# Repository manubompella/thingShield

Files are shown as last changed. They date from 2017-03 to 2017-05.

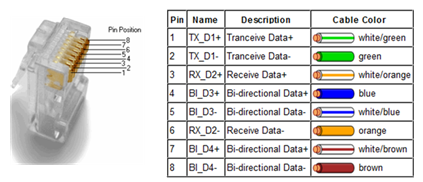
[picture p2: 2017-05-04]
thingShield-Bot/Reference/509802d016bce918a6f6cb5cf38a3232.png

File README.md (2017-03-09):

# Arduino XBee shield

The Arduino shield is designed to be used for multiple use cases without redesigning the hardware. 

## Platform Features

 * [XBee Compatible Socket](https://www.sparkfun.com/datasheets/Wireless/Zigbee/XBee-Dimensional.pdf)
 * TTL to CMOS level shifter
 * Compatible with UNO R3 headers
 * Ability to support multiple thingBot platforms
 
## Maintainers

The Arduino Xbee shield is maintained by thingTronics Innovations.

Main contributor:
 * Manohar Bompella @<manohar.bompella@thingtronics.com>
 * Lovelesh Patel @<lovelesh.patel@thingtronics.com>

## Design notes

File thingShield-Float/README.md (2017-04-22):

# thingFloat-Shield

The Arduino shield is designed to be used for water level floats without redesigning the hardware. 

## Platform Features

 * Compatible with UNO R3/MEGA headers
 
## Maintainers

The thingFloat-Shield is maintained by thingTronics Innovations.

Main contributor:
 * Manohar Bompella @<manohar.bompella@thingtronics.com>
 * Lovelesh Patel @<lovelesh.patel@thingtronics.com>

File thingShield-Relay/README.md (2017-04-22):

# thingRelay-Shield

The Arduino shield is designed to be used for relay without redesigning the hardware. 

## Platform Features

 * Compatible with UNO R3/MEGA headers
 
## Maintainers

The thingRelay-Shield is maintained by thingTronics Innovations.

Main contributor:
 * Manohar Bompella @<manohar.bompella@thingtronics.com>
 * Lovelesh Patel @<lovelesh.patel@thingtronics.com>

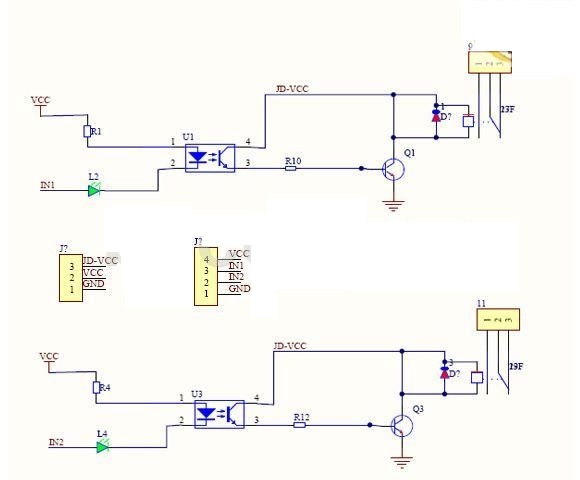
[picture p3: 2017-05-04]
thingShield-Float/Reference/schematic-1.jpg

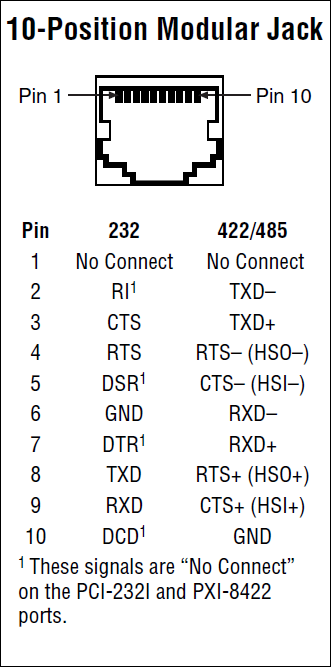
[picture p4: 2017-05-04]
thingShield-Bot/Reference/10PosModJack.png

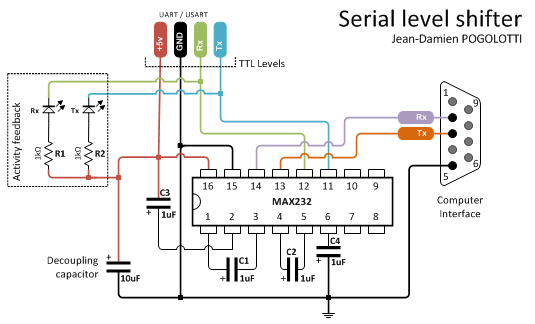
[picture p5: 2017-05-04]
thingShield-Bot/Reference/1449150794_serialshifter.png

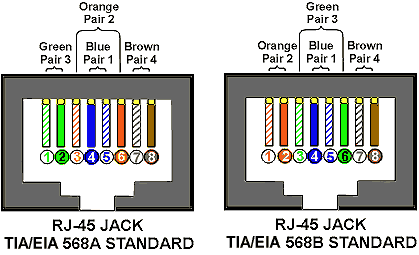
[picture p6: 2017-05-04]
thingShield-Bot/Reference/RJ45-b.gif

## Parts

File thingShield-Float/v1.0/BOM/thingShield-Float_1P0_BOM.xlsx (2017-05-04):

thingShield-Float v1.0
BILL OF MATERIALS
Item | Quantity | Reference | Value |  | Footprint | 1 | 100 | 500 | 1000 |  | 10 PCB | 100 PCB | 1000 PCB
1 | 1 | P1 | PWR_JMPR |  | Pin_Headers:Pin_Header_Straight_1x02_Pitch2.54mm | 7.7 | 2.8 | 2.8 | 2.59 |  | 7.7 | 2.8 | 2.59
2 | 1 | P10 | CON1 | http://www.mouser.in/Phoenix-Contact/ | Connectors:gmkds_3-3-5,08 | 69.3 | 62.02 | 53.48 | 49.35 |  | 69.3 | 62.02 | 49.35
3 | 1 | P11 | CON2 | http://www.mouser.in/Phoenix-Contact/ | Connectors:gmkds_3-3-5,08 | 69.3 | 62.02 | 53.48 | 49.35 |  | 69.3 | 62.02 | 49.35
4 | 1 | P12 | CON3 | http://www.mouser.in/Phoenix-Contact/ | Connectors:gmkds_3-3-5,08 | 69.3 | 62.02 | 53.48 | 49.35 |  | 69.3 | 62.02 | 49.35
5 | 1 | P2,P6 | JUMP1_CON1_PIN3 |  | Pin_Headers:Pin_Header_Straight_2x03_Pitch2.54mm | 160.3 | 115.5 | 109.2 | 101.5 |  | 160.3 | 115.5 | 101.5
6 | 1 | P3,P7 | JUMP2_CON2_PIN3 |  | Pin_Headers:Pin_Header_Straight_2x03_Pitch2.54mm | 160.3 | 115.5 | 109.2 | 101.5 |  | 160.3 | 115.5 | 101.5
7 | 1 | P4,P8 | JUMP3_CON3_PIN1 |  | Pin_Headers:Pin_Header_Straight_2x04_Pitch2.54mm | 160.3 | 115.5 | 109.2 | 101.5 |  | 160.3 | 115.5 | 101.5
8 | 1 | P5,P9 | JUMP4_CON3_PIN3 |  | Pin_Headers:Pin_Header_Straight_2x03_Pitch2.54mm | 160.3 | 115.5 | 109.2 | 101.5 |  | 160.3 | 115.5 | 101.5
9 | 6 | R1 R2 R3 R4 R5 R6 | 10K |  | Resistors_SMD:R_0805_HandSoldering | 7.7 | 2.8 | 2.8 | 2.59 |  | 46.2 | 16.8 | 15.54
10 | 1 | U1 | ARDUINO_MEGA_SHIELD |  | Arduino:ARDUINO_MEGA_SHIELD |  |  |  |  |  | 0 | 0 | 0
11 | 1 |  |  | http://www.mouser.in/schmartboard/ |  | 350 | 200 | 150 | 100 |  | 350 | 200 | 100
12 | 5 |  |  | http://www.mouser.in/sparkfun/ |  | 35 | 20 | 15 | 10 |  | 175 | 100 | 50
13 | 1 |  |  | http://www.mouser.in/sparkfun/ |  | 35 | 20 | 15 | 10 |  | 35 | 20 | 10
 |  |  |  |  |  |  |  |  |  | TOTAL = | 1463 | 987.66 | 732.18

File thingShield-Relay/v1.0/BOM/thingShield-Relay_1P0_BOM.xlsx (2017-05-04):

thingShield-Relay v1.0
BILL OF MATERIALS
Item | Quantity | Reference | Value | DESC | MFG_NAME | MPN | Package | Footprint | 1 | 100 | 500 | 1000 |  | 10 PCB | 100 PCB | 1000 PCB
1 | 2 | D1 D2 | YELLOW | Yellow led for Relay trigger indication | Kingbright | AP2012SRCPRV | 805 | LEDs:LED_0805 | 7.7 | 2.8 | 2.8 | 2.59 |  | 15.4 | 5.6 | 5.18
2 | 2 | D3 D4 | znr diode | Zener Diodes 33 Volt 0.5 Watt | Vishay Semiconductors (http://www.mouser.in/vishaysemiconductors/) | 1N5257B-TR | TH | Diodes_ThroughHole:D_5W_P10.16mm_Horizontal | 11.2 | 4.13 | 3.43 | 2.31 |  | 22.4 | 8.26 | 4.62
3 | 1 | P1 | MEGA_PIN_MAPING | 1X12 2.54 mm Male TH Straight | Worth Elektronic | 61300211121 |  | Pin_Headers:Pin_Header_Straight_1x12_Pitch2.54mm | 8.4 | 7.42 | 6.3 | 6.23 |  | 8.4 | 7.42 | 6.23
4 | 1 | P2 | RELAY_2_PIN_HEADER | 1X12 2.54 mm Male TH Straight | Worth Elektronic | 61300211121 |  | Pin_Headers:Pin_Header_Straight_1x12_Pitch2.54mm | 8.4 | 7.42 | 6.3 | 6.23 |  | 8.4 | 7.42 | 6.23
5 | 1 | P3 | 5V_TO_RELAY_VCC_CONN | 1X2 2.54 mm Male TH Straight | Worth Elektronic | 61300211121 |  | Pin_Headers:Pin_Header_Straight_1x02_Pitch2.54mm | 8.4 | 7.42 | 6.3 | 6.23 |  | 8.4 | 7.42 | 6.23
6 | 1 | P4 | RELAY_1_PIN_HEADER | 1X12 2.54 mm Male TH Straight | Worth Elektronic | 61300211121 |  | Pin_Headers:Pin_Header_Straight_1x12_Pitch2.54mm | 8.4 | 7.42 | 6.3 | 6.23 |  | 8.4 | 7.42 | 6.23
7 | 1 | P5 | RELAY_2_CON | 3 Pin Screw Connector 5.08mm | Phoenix Contact (http://www.mouser.in/Phoenix-Contact/) | 1729128 | TH | Connectors:gmkds_3-3-5,08 | 69.3 | 62.02 | 53.48 | 49.35 |  | 69.3 | 62.02 | 49.35
8 | 1 | P6 | RELAY_1_CON | 3 Pin Screw Connector 5.08mm | Phoenix Contact (http://www.mouser.in/Phoenix-Contact/) | 1729128 | TH | Connectors:gmkds_3-3-5,08 | 69.3 | 62.02 | 53.48 | 49.35 |  | 69.3 | 62.02 | 49.35
9 | 1 | P7 | EXT_PWR | 2 Pin Screw Connector 5.08mm | Phoenix Contact (http://www.mouser.in/Phoenix-Contact/) | 1729128 | TH | Connectors:gmkds_3-2-5,08 | 69.3 | 62.02 | 53.48 | 49.35 |  | 69.3 | 62.02 | 49.35
10 | 2 | Q1 Q2 | MMBT3904 | Bipolar Transistors - BJT SOT-23 NPN GEN PUR | Fairchild Semiconductor | MMBT3904 | SMD SOT-23 | TO_SOT_Packages_SMD:SOT-23 | 9.8 | 3.36 | 3.36 | 2.24 |  | 19.6 | 6.72 | 4.48
11 | 2 | R1 R2 | 1K | Current Sense Resistors - SMD 0805 0.002ohm 1% AEC-Q200 | ROHM Semiconductor | PMR10EZPFV2L00 | 805 | Resistors_SMD:R_0805_HandSoldering | 7.7 | 2.8 | 2.8 | 2.59 |  | 15.4 | 5.6 | 5.18
12 | 2 | R3 R4 | 510E | Current Sense Resistors - SMD 0805 0.002ohm 1% AEC-Q200 | ROHM Semiconductor | PMR10EZPFV2L00 | 805 | Resistors_SMD:R_0805_HandSoldering | 7.7 | 2.8 | 2.8 | 2.59 |  | 15.4 | 5.6 | 5.18
13 | 2 | RL1 ,RL2 | RELAY_1, RELAY_2 | songle 5v relay | Songle | SRD-03VDC-SL-C | TH | relays:Songle_SRS-03VDC-SL | 50 | 40 | 40 | 30 |  | 100 | 80 | 60
14 | 1 | U1 | ARDUINO_MEGA_SHIELD | arduino mega shield(DNM) | DNM | DNM | DNM | Arduino:ARDUINO_MEGA_SHIELD |  |  |  |  |  | 0 | 0 | 0
15 | 2 | U2 U3 | LTV-817 | 4 PIN DIP PHOTOTRANSISTOR PHOTOCOUPLER (PC817 OR FL817) | Sharp Microelectronics (http://www.mouser.in/Sharpsma) | PC81711NIP0X (http://www.mouser.in/ProductDetail/Sharp-Microelectronics/PC81711NIP0X/?qs=sGAEpiMZZMtt1NDYJdFZeKr6f6WqZ7Gd) | TH | PC817:DIL04 | 56.7 | 31.5 | 27 | 25 |  | 113.4 | 63 | 50
16 | 1 |  |  | Dual row stackble female headers 18x2 | SchmartBoard (http://www.mouser.in/schmartboard/) | 920-0103-01 | TH |  | 350 | 200 | 150 | 100 |  | 350 | 200 | 100
17 | 5 |  |  | single row stackble female headers 8x1 | SparkFun (http://www.mouser.in/sparkfun/) | PRT-11376 | TH |  | 35 | 20 | 15 | 10 |  | 175 | 100 | 50
18 | 1 |  |  | single row stackble female headers 10x1 | SparkFun (http://www.mouser.in/sparkfun/) | PRT-11376 | TH |  | 35 | 20 | 15 | 10 |  | 35 | 20 | 10
 |  |  |  |  |  |  |  |  |  |  |  |  | TOTAL = | 1103.1 | 710.52 | 467.61

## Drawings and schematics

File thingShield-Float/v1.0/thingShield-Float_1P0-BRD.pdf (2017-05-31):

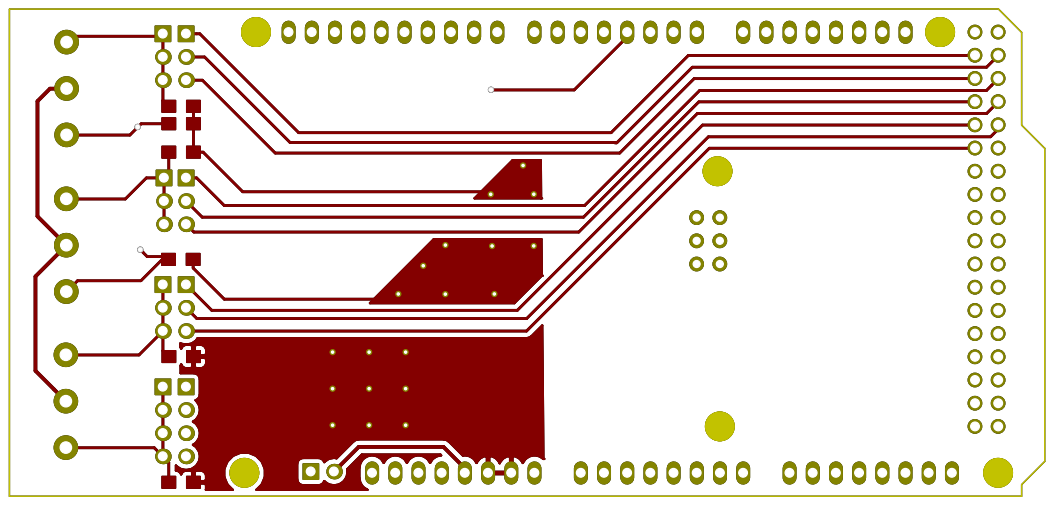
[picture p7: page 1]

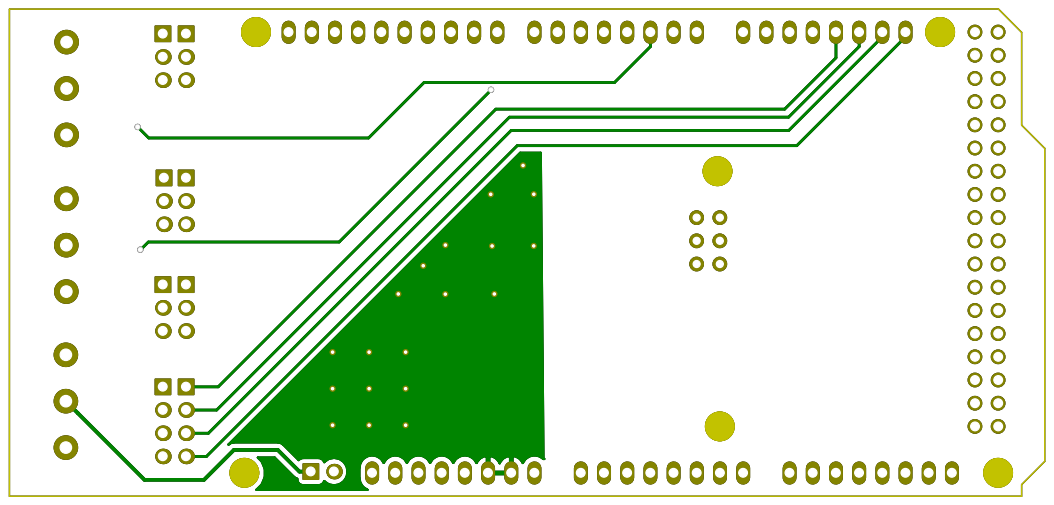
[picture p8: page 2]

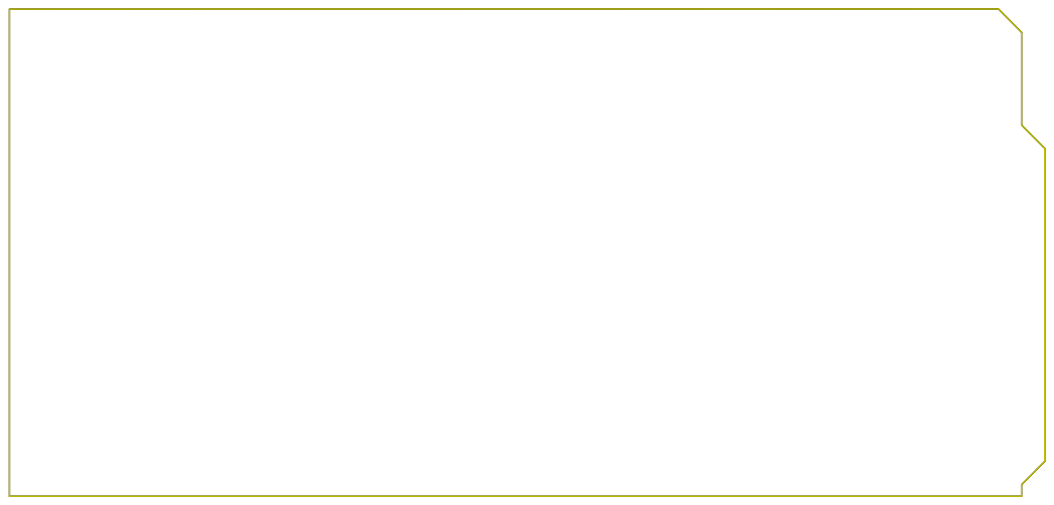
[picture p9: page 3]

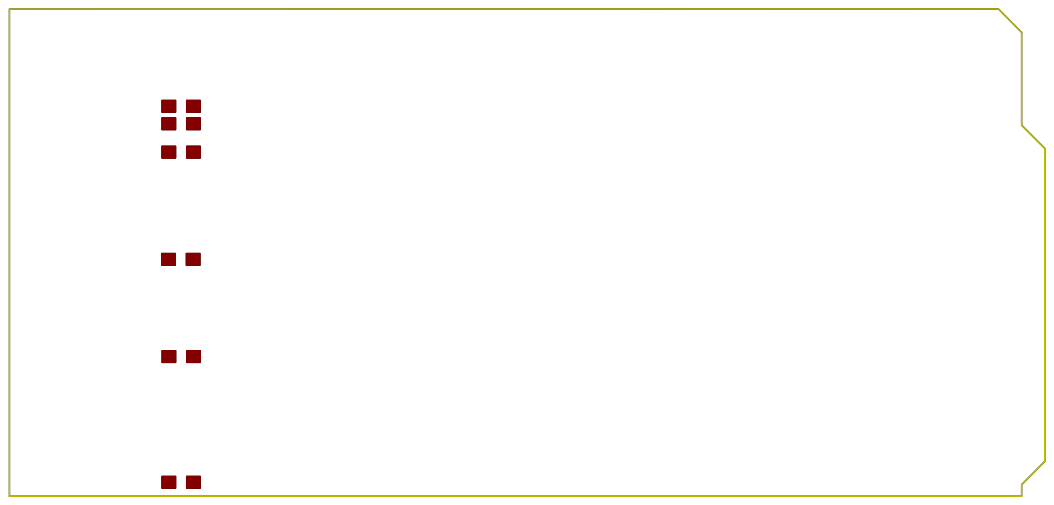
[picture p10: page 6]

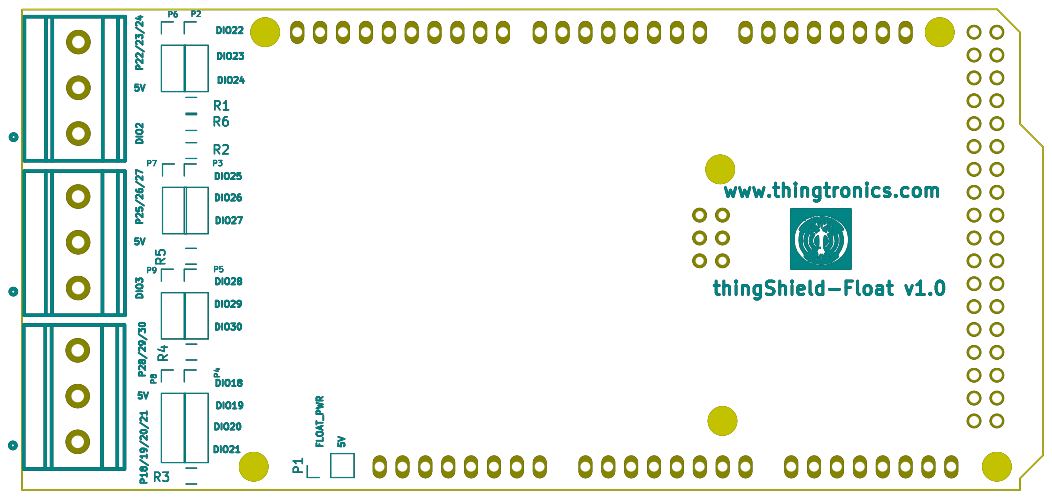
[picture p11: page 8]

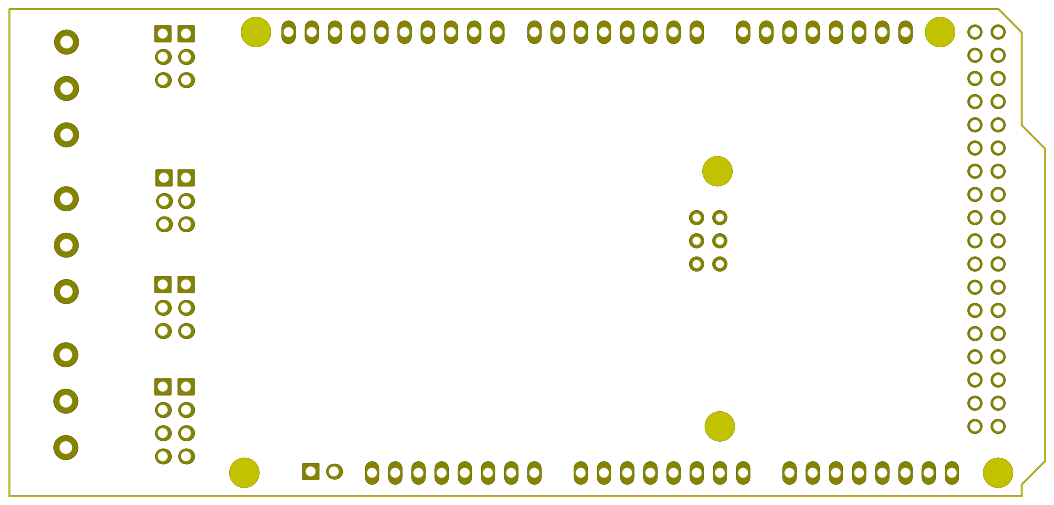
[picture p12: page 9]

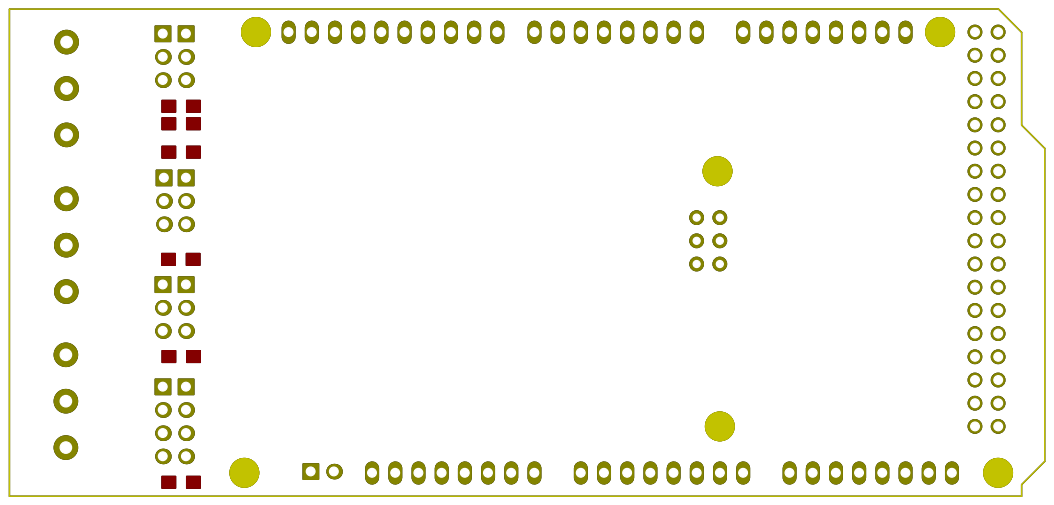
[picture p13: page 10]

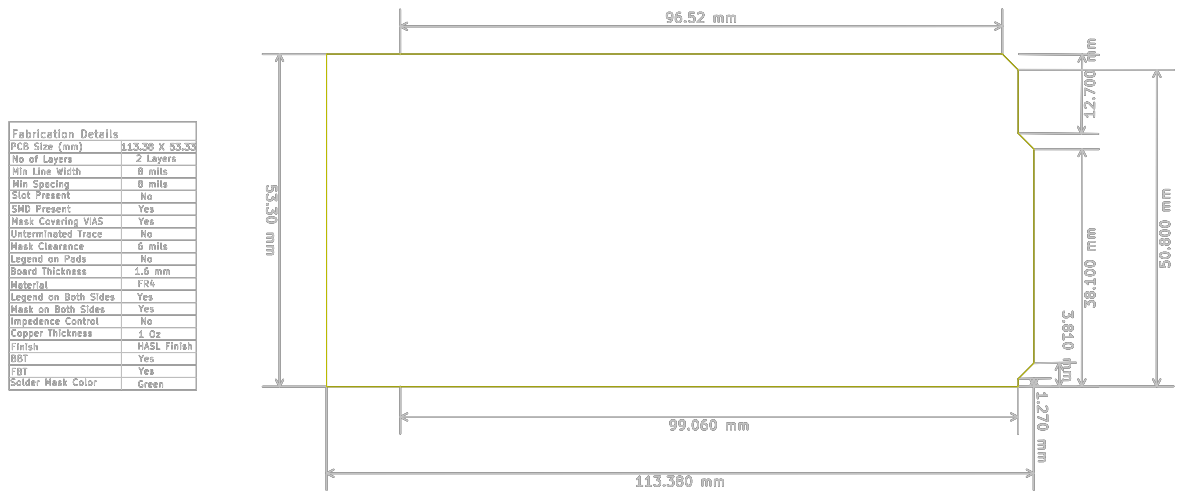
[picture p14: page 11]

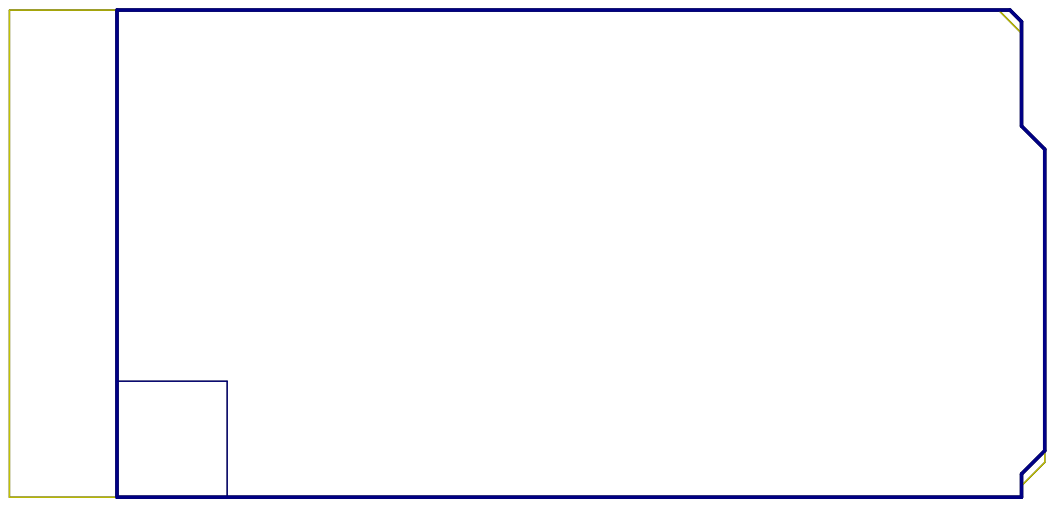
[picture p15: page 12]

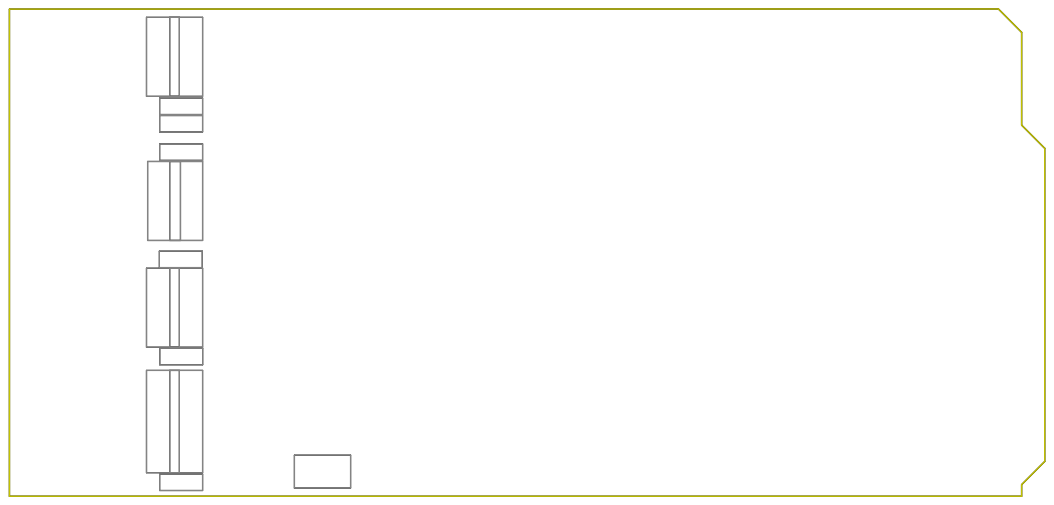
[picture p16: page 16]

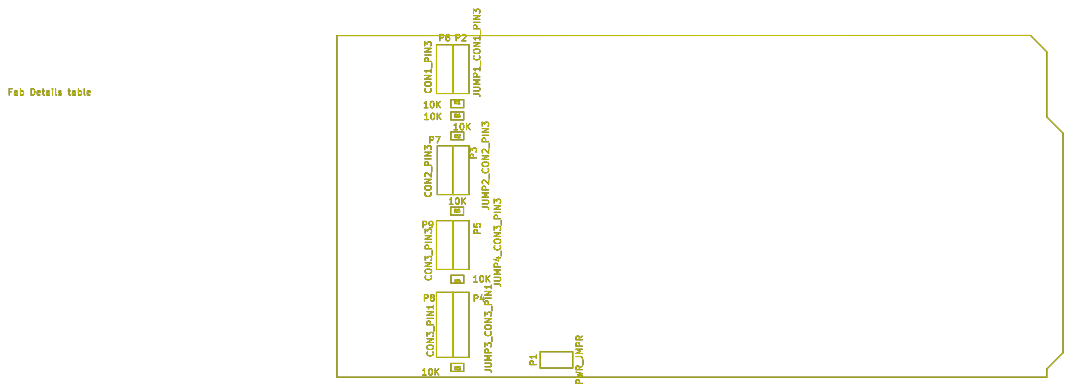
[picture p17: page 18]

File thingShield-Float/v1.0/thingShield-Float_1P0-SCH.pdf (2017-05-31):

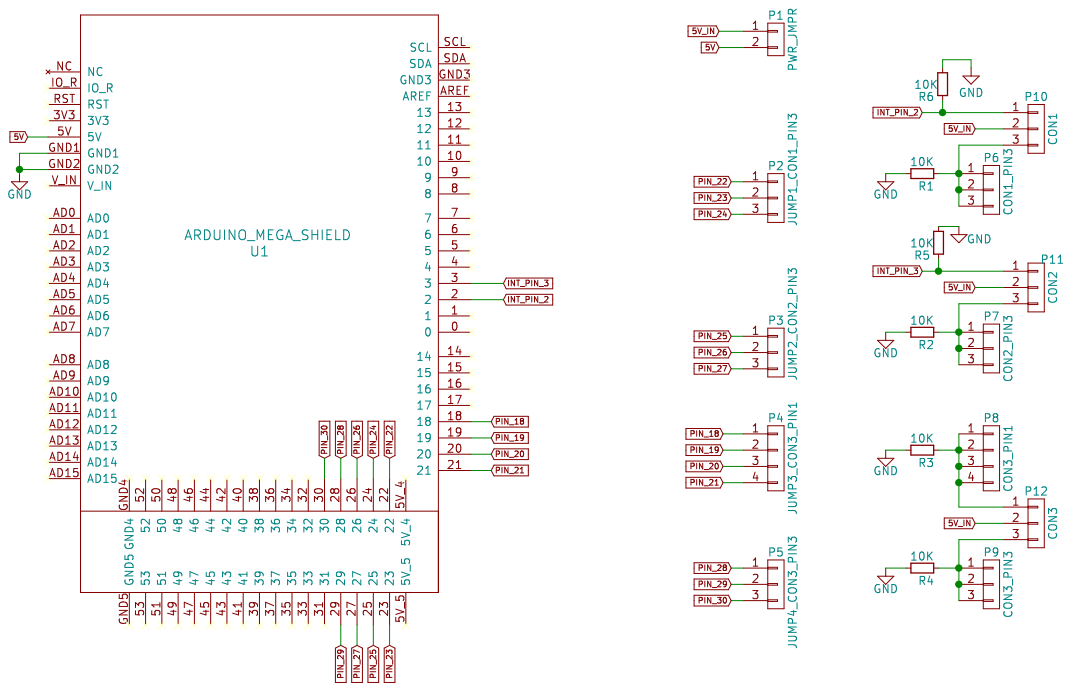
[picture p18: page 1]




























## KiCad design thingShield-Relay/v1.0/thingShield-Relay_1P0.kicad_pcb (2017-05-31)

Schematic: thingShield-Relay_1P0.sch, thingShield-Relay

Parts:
D1, D2: YELLOW; LED_0805
D3, D4: znr diode; D_5W_P10.16mm_Horizontal
P1: MEGA_PIN_MAPING; Pin_Header_Straight_1x12_Pitch2.54mm
P2: RELAY_2_PIN_HEADER; Pin_Header_Straight_1x12_Pitch2.54mm
P3: 5V_TO_RELAY_VCC_CONN; Pin_Header_Straight_1x02_Pitch2.54mm
P4: RELAY_1_PIN_HEADER; Pin_Header_Straight_1x12_Pitch2.54mm
P5: RELAY_2_CON; gmkds_3-3-5,08
P6: RELAY_1_CON; gmkds_3-3-5,08
P7: EXT_PWR; gmkds_3-2-5,08
Q1, Q2: MMBT3904; SOT-23
R1, R2: 1K; R_0805_HandSoldering
R3, R4: 510E; R_0805_HandSoldering
RL1: RELAY_1; Songle_SRS-03VDC-SL
RL2: RELAY_2; Songle_SRS-03VDC-SL
U1: ARDUINO_MEGA_SHIELD
U2, U3: LTV-817; DIL04

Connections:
5V: P3.2, U1.5V
GND: P7.2, Q1.2 (E), Q2.2 (E), U1.GND1
unnamed: D1.2 (A), U2.2
unnamed: D2.2 (A), U3.2
unnamed: D3.2 (A), Q1.3 (C), RL1.1
unnamed: D4.2 (A), Q2.3 (C), RL2.1
unnamed: P1.1, U1.13
unnamed: P1.2, U1.12
unnamed: P1.3, U1.11
unnamed: P1.4, U1.10
unnamed: P1.5, U1.9
unnamed: P1.6, U1.8
unnamed: P1.7, U1.7
unnamed: P1.8, U1.6
unnamed: P1.9, U1.5
unnamed: P1.10, U1.4
unnamed: P1.11, U1.3
unnamed: P1.12, U1.2
unnamed: P5.1, RL2.4
unnamed: P5.2, RL2.3
unnamed: P5.3, RL2.5
unnamed: P6.1, RL1.4
unnamed: P6.2, RL1.3
unnamed: P6.3, RL1.5
unnamed: Q1.1 (B), R3.1
unnamed: Q2.1 (B), R4.1
unnamed: R1.1, U2.1
unnamed: R2.1, U3.1
unnamed: R3.2, U2.3
unnamed: R4.2, U3.3
RELAY_1: D1.1 (K), P4.1, P4.2, P4.3, P4.4, P4.5, P4.6, P4.7, P4.8, P4.9, P4.10, P4.11, P4.12
RELAY_2: D2.1 (K), P2.1, P2.2, P2.3, P2.4, P2.5, P2.6, P2.7, P2.8, P2.9, P2.10, P2.11, P2.12
RELAY_VCC: D3.1 (K), D4.1 (K), P3.1, P7.1, R1.2, R2.2, RL1.2, RL2.2, U2.4, U3.4

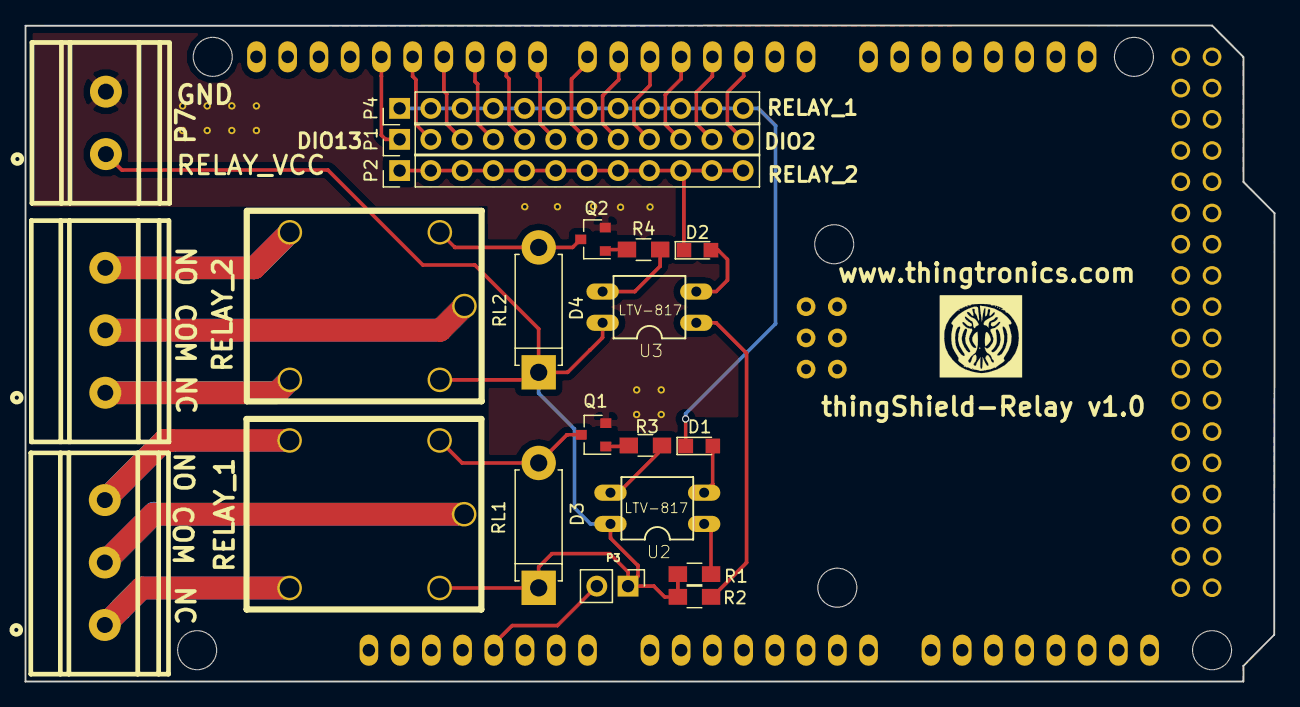
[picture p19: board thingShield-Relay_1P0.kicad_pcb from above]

Board: 2 copper layers, 101.6 x 53.4 mm, 22 parts (0 on the bottom side), 33 nets.

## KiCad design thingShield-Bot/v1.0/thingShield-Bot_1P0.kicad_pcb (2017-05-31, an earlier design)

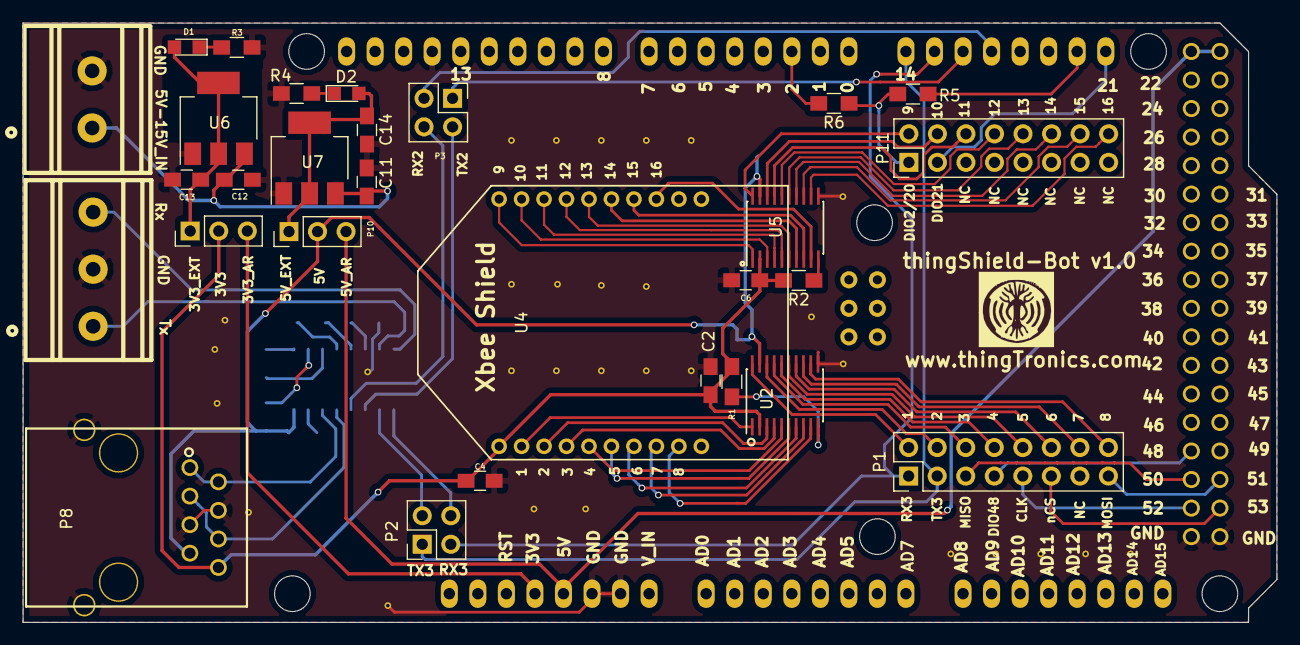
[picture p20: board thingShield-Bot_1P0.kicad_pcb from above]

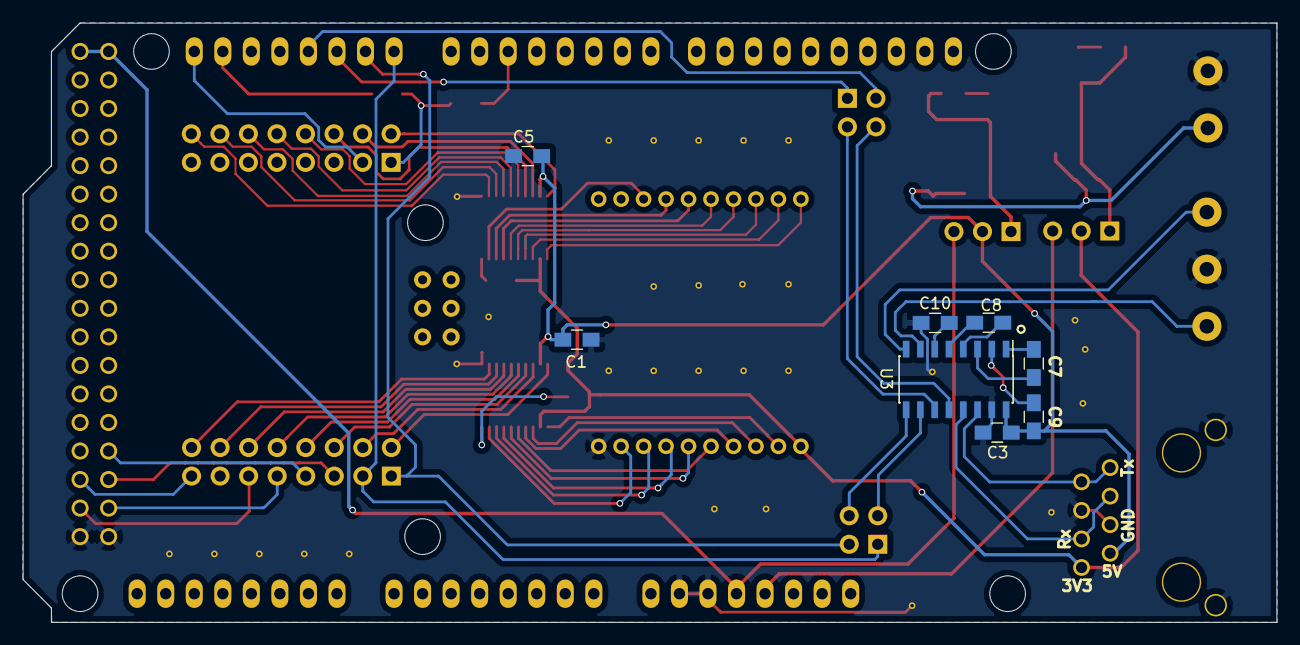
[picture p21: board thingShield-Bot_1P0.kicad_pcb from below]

Board: 2 copper layers, 111.6 x 53.3 mm, 38 parts (8 on the bottom side), 71 nets.

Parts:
C1, C2, C5, C6: 0.1uF; C_0805_HandSoldering
C3, C4, C7, C8, C9, C10: 1uF; C_0805_HandSoldering
C11, C12, C13, C14: 10uF; C_0805_HandSoldering
D1, D2: PWR; LED_0805
P1: LEFT_CONN_02X08; Pin_Header_Straight_2x08_Pitch2.54mm
P2: RS232_JMPR_2; Pin_Header_Straight_2x02_Pitch2.54mm
P3: RS232_JMPR_1; Pin_Header_Straight_2x02_Pitch2.54mm
P5: CONN_COM; gmkds_3-3-5,08
P6: JMPR_3V3; Pin_Header_Straight_1x03_Pitch2.54mm
P7: PWR_CONN; gmkds_3-2-5,08
P8: CNT-RJ45_10PIN; RJ45_18.7 X 15.84
P10: JMPR_5V; Pin_Header_Straight_1x03_Pitch2.54mm
P11: RIGHT_CONN_02X08; Pin_Header_Straight_2x08_Pitch2.54mm
R1, R2: 10K; R_0805_HandSoldering
R3, R4: 1K; R_0805_HandSoldering
R5, R6: 0E; R_0805_HandSoldering
U1: ARDUINO_MEGA_SHIELD
U2, U5: TXB0108; SSOP-20_4.4x6.5mm_Pitch0.65mm_longPads
U3: MAX232; SOIC-16_3.9x9.9mm_Pitch1.27mm
U4: XBEE_MODULE; XBee_Socket_without_Jtag
U6: LM1117-3.3; SOT-223
U7: LM1117-5.0; SOT-223

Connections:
3V3: C2.1, C4.1, C6.1, P6.2, P8.8, R1.2, R2.2, U2.2, U4.1, U5.2
3V3_AR: P6.3, U1.3V3
3V3_EXT: C13.1, D1.2, P6.1, U6.2, U6.4
5V: C1.1, C3.1, C5.1, C9.1, P8.7, P10.2, U2.19, U3.16, U5.19
5V_AR: P10.3, U1.5V, U1.5V_4, U1.5V_5
5V_EXT: C14.1, D2.2, P10.1, U7.2, U7.4
CLK: P1.9, U1.52
EXT_PWR_IN: C11.1, C12.1, P7.1, U6.3, U7.3
GND: C1.2, C2.2, C3.2, C4.2, C5.2, C6.2, C10.1, C11.2, C12.2, C13.2, C14.2, P5.2, P7.2, P8.4, P8.5, P8.9, P8.10, R3.2, R4.2, U1.GND1, U1.GND2, U1.GND3, U1.GND4, U1.GND5, U2.11, U3.15, U4.10, U5.11, U6.1, U7.1
INT_2: R6.2, U1.2
MISO: P1.5, U1.50
MOSI: P1.15, U1.51
unnamed: C7.1, U3.1
unnamed: C7.2, U3.3
unnamed: C8.1, U3.4
unnamed: C8.2, U3.5
unnamed: C9.2, U3.2
unnamed: C10.2, U3.6
unnamed: D1.1, R3.1
unnamed: D2.1, R4.1
unnamed: P1.2, U2.20
unnamed: P1.4, U2.18
unnamed: P1.6, U2.17
unnamed: P1.8, U2.16
unnamed: P1.10, U2.15
unnamed: P1.12, U2.14
unnamed: P1.14, U2.13
unnamed: P1.16, U2.12
unnamed: P2.2, U3.10
unnamed: P2.4, U3.9
unnamed: P3.2, U3.11
unnamed: P3.4, U3.12
unnamed: P11.1, R5.1, R6.1
unnamed: P11.2, U5.20
unnamed: P11.4, U5.18
unnamed: P11.6, U5.17
unnamed: P11.8, U5.16
unnamed: P11.10, U5.15
unnamed: P11.12, U5.14
unnamed: P11.14, U5.13
unnamed: P11.16, U5.12
unnamed: R1.1, U2.10
unnamed: R2.1, U5.10
unnamed: U2.1, U4.2
unnamed: U2.3, U4.3
unnamed: U2.4, U4.4
unnamed: U2.5, U4.5
unnamed: U2.6, U4.6
unnamed: U2.7, U4.7
unnamed: U2.8, U4.8
unnamed: U2.9, U4.9
unnamed: U4.13, U5.9
unnamed: U4.14, U5.8
unnamed: U4.15, U5.7
unnamed: U4.16, U5.6
unnamed: U4.17, U5.5
unnamed: U4.18, U5.4
unnamed: U4.19, U5.3
unnamed: U4.20, U5.1
RX2: P3.3, U1.17
RX3: P1.1, P2.3, U1.15
RX_232_1: P8.3, P8.6, U3.13
RX_232_2: P5.3, U3.8
SCL: P11.3, U1.21
SDA: R5.2, U1.20
TX2: P3.1, U1.16
TX3: P1.3, P2.1, U1.14
TX_232_1: P8.1, P8.2, U3.14
TX_232_2: P5.1, U3.7
nCS: P1.11, U1.53
nRESET: P1.7, U1.48

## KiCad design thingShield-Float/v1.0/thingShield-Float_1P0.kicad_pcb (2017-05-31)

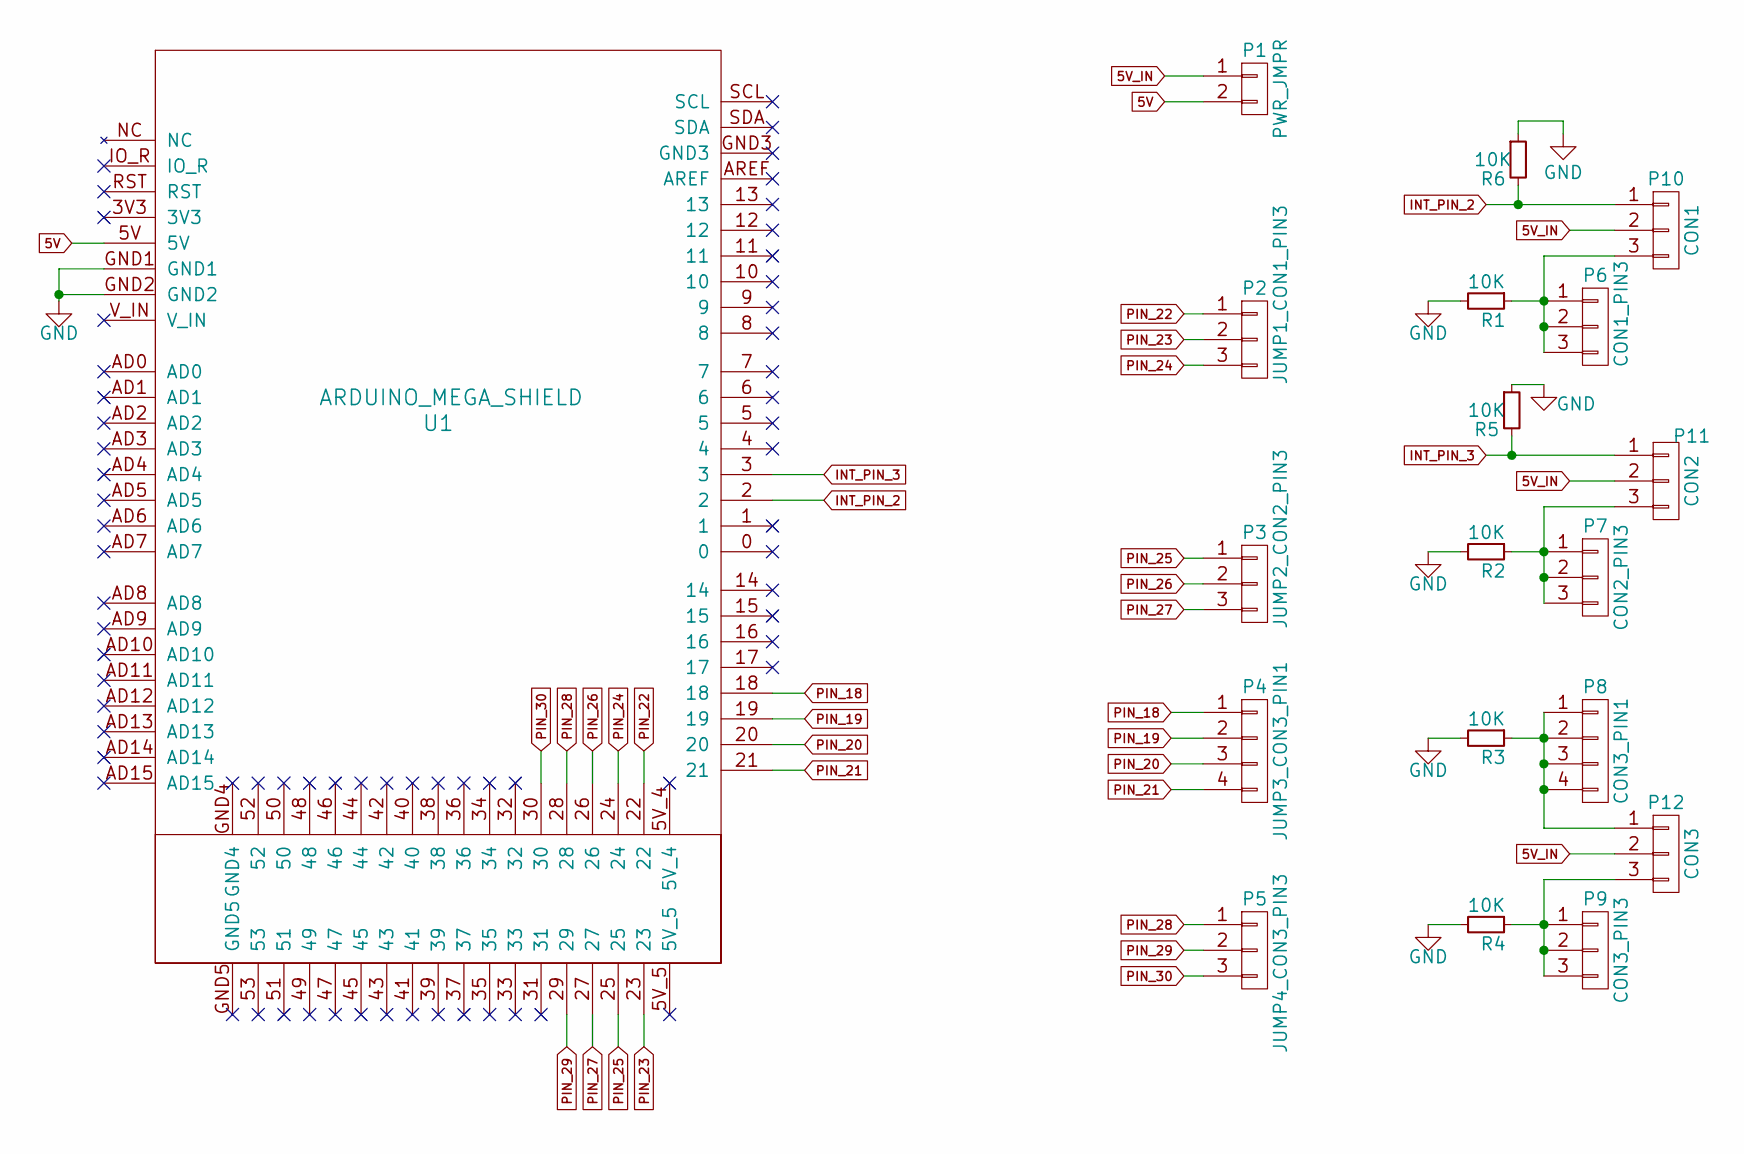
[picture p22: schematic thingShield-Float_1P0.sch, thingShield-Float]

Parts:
P1: PWR_JMPR; Pin_Header_Straight_1x02_Pitch2.54mm
P2: JUMP1_CON1_PIN3; Pin_Header_Straight_1x03_Pitch2.54mm
P3: JUMP2_CON2_PIN3; Pin_Header_Straight_1x03_Pitch2.54mm
P4: JUMP3_CON3_PIN1; Pin_Header_Straight_1x04_Pitch2.54mm
P5: JUMP4_CON3_PIN3; Pin_Header_Straight_1x03_Pitch2.54mm
P6: CON1_PIN3; Pin_Header_Straight_1x03_Pitch2.54mm
P7: CON2_PIN3; Pin_Header_Straight_1x03_Pitch2.54mm
P8: CON3_PIN1; Pin_Header_Straight_1x04_Pitch2.54mm
P9: CON3_PIN3; Pin_Header_Straight_1x03_Pitch2.54mm
P10: CON1; gmkds_3-3-5,08
P11: CON2; gmkds_3-3-5,08
P12: CON3; gmkds_3-3-5,08
R1, R2, R3, R4, R5, R6: 10K; R_0805_HandSoldering
U1: ARDUINO_MEGA_SHIELD

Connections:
5V: P1.2, U1.5V
5V_IN: P1.1, P10.2, P11.2, P12.2
GND: R1.2, R2.2, R3.2, R4.2, R5.1, R6.1, U1.GND1, U1.GND2
INT_PIN_2: P10.1, R6.2, U1.2
INT_PIN_3: P11.1, R5.2, U1.3
unnamed: P6.1, P6.2, P6.3, P10.3, R1.1
unnamed: P7.1, P7.2, P7.3, P11.3, R2.1
unnamed: P8.1, P8.2, P8.3, P8.4, P12.1, R3.1
unnamed: P9.1, P9.2, P9.3, P12.3, R4.1
PIN_18: P4.1, U1.18
PIN_19: P4.2, U1.19
PIN_20: P4.3, U1.20
PIN_21: P4.4, U1.21
PIN_22: P2.1, U1.22
PIN_23: P2.2, U1.23
PIN_24: P2.3, U1.24
PIN_25: P3.1, U1.25
PIN_26: P3.2, U1.26
PIN_27: P3.3, U1.27
PIN_28: P5.1, U1.28
PIN_29: P5.2, U1.29
PIN_30: P5.3, U1.30

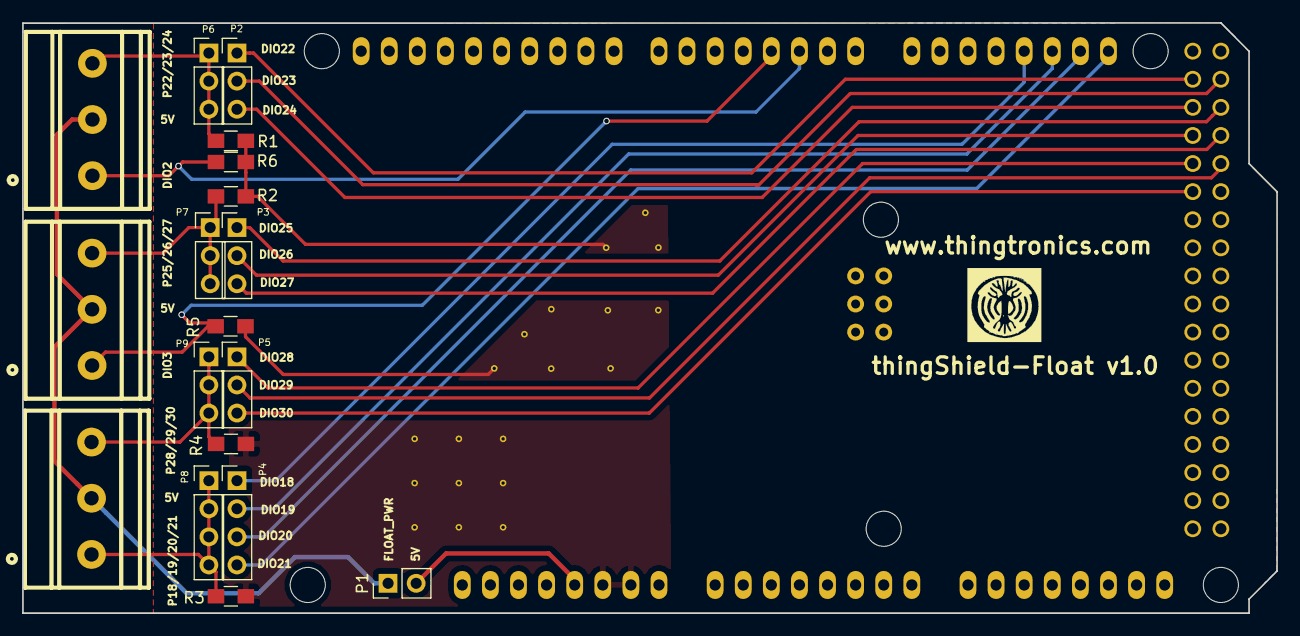
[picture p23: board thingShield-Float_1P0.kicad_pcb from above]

Board: 2 copper layers, 113.4 x 53.4 mm, 19 parts (0 on the bottom side), 22 nets.

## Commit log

2017-03-09 initiated the schematic design
    [Arduino XBEE_LoRa shield.kicad_pcb, Arduino XBEE_LoRa shield.sch, Arduino thingBot Shield_1P0.sch]
2017-05-04 three thingShield projects added
    the following thingShield added
    -> thingBot-Shield
    -> thingFloat-Shield
    -> thingRelay-Shield
    in each of them Bom,gerbers,reference,schematic and layout files added
    [Relay_shield-B.Cu.gbr, Relay_shield-B.Fab.gbr, Relay_shield-B.Mask.gbr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]
2017-05-04 three thingBot-shield projects added
    following shields added
    in each one bom ,reference,gerbers files added
    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
    [Relay_shield-B.Cu.gbr, Relay_shield-B.Fab.gbr, Relay_shield-B.Mask.gbr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]
2017-05-27 Verified Bot and float shields
    [Relay_shield.xlsx, Sensor_shield.xlsx, thingShield-Bot.xlsx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]
2017-05-27 verified all the shields
    [thingShield-Bot_1P0_BOM.xlsx, thingShield-Float_1P0_BOM.xlsx, thingShield-Relay_1P0.kicad_pcb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]
2017-05-31 thingBot-Shieldv2.0 files added
    thingBot-Shieldv2.0 following files added
    - schematic
    - Layout
    - gerber files added
    [thingShield-Bots-B.Cu.gbr, thingShield-Bots-B.Fab.gbr, thingShield-Bots-B.Mask.gbr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]
2017-05-31 removed v2.0
    removed v2.0
    [thingShield-Bots-B.Cu.gbr, thingShield-Bots-B.Fab.gbr, thingShield-Bots-B.Mask.gbr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]
2017-05-31 thingShield-Bot v2.0 files added
    thingShield-Bot v2.0 following things Added
    - shcematic
    - layout
    - gerbers
    [thingShield-Bots-B.Cu.gbr, thingShield-Bots-B.Fab.gbr, thingShield-Bots-B.Mask.gbr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]
